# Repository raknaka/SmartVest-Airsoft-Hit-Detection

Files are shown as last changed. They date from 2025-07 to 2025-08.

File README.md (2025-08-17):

# 🎯 SmartVest - Airsoft Hit Detection System  

**SmartVest** is a smart wearable system designed for airsoft games and tactical training scenarios.  
It provides **real-time hit detection** by sensing BB pellet or rubber projectile impacts through an array of pressure and vibration sensors.  
Inspired by video game mechanics, SmartVest delivers immersive and measurable training by mapping impact zones and giving instant feedback to the player or trainer.  

---

## 🧩 Project Mockup  

Here's a visual mockup of the SmartVest system design:  

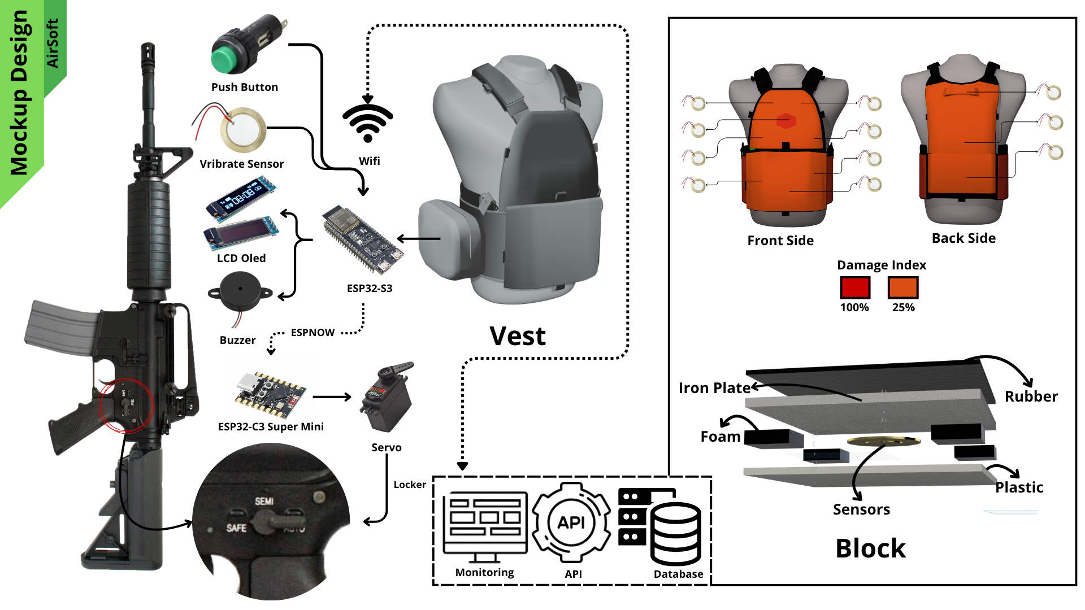
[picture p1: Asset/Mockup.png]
SmartVest Design Mockup
  

---

## 💡 What Does It Do?  

SmartVest detects and classifies hits from projectiles (BBs or rubber bullets) on a player’s body using multiple force and vibration sensors embedded within a vest. It is especially designed to:  

- **Track and identify projectile impacts**  
- **Map hit locations across multiple zones**  
- **Differentiate real hits from fake or foreign object contacts**  
- **Deliver immediate feedback (visual/audio)**  
- **Log and transmit hit data to a central server or controller**  

---

## 🚀 Features  

- 🔹 **Multi-zone sensor detection** across the vest  
- 🔹 **Impact classification** (projectile vs. non-projectile)  
- 🔹 **Wireless communication options**:  
  - **ESP-NOW** → ultra-fast (1–2 ms latency) between vest & gun  
  - **Wi-Fi** → real-time logging to server/dashboard  
  - **LoRa (optional)** → long-range outdoor operations  
- 🔹 **Customizable & modular system** → supports different body sizes, teams, and modes  
- 🔹 **Game-style feedback** → LEDs, buzzer, vibration  
- 🔹 **Weapon lock system** → disables gun when player is “eliminated”  

---

## ⚙️ System Architecture  

- **Vest Module (ESP32)**  
  Processes sensor data, tracks health, and gives feedback via buzzer, LEDs, or vibration.  

- **Weapon Module (ESP32-C3 Mini + Servo)**  
  Automatic lock/unlock mechanism to prevent eliminated players from shooting.  

- **Monitoring Dashboard (Server/Raspberry Pi)**  
  Displays real-time player health, team stats, and hit locations.  

---

## 🧪 Testing & Results  

### Projectile & Airsoft Testing  
- Works best at **5–10 m**.  
- Piezo sensors generate up to **14V**, while ESP32 ADC max is **3.3V** (4095).  
- Tested with **SIG Sauer P226 MK25 GBB handgun** (~100 m/s muzzle velocity).  
- Reliable detection at 5 m distance.  

### Heatmap Analysis  
- A **grid test** (60×60 mm and 100×200 mm) was used to simulate projectile impacts on the vest pad.  
- **Heatmaps** were generated using Python visualization to show impact distribution:  
  - **Center areas** (closest to the sensor) produce the highest ADC readings.  
  - **Edges of the pad** show weaker signals, sometimes too low to be detected.  
  - Vibrations propagate to neighboring pads, but the **highest ADC value always corresponds to the direct hit pad**.  
- This proves SmartVest can **localize hits accurately** by identifying the strongest signal zone.  

*(Add images of heatmap here, e.g. 60x60 grid & 100x200 pad results)*  

### ESP-NOW Communication  
- Average latency: **1–2 ms**, with occasional spikes up to 45 ms due to interference.  
- Still fast and stable enough for **real-time weapon lock & feedback**.  

---

## 📂 Repository Contents  

- `firmware/` → ESP32 & ESP32-C3 source code  
- `hardware/` → PCB design files  
- `docs/` → diagrams, mockups, and test results  

---

## 📸 Prototype & Dashboard  

(Add your prototype photos, PCB screenshots, heatmap images, and monitoring UI here)  

---

## ⚡ Conclusion  

SmartVest integrates **real-time hit detection**, **automatic weapon lock**, and **centralized monitoring** into one system.  
Through **heatmap testing**, the system shows reliable hit localization and clear differentiation of impact zones.  
It enhances **fairness, sportmanship, and immersion** in airsoft games by combining IoT technology with game-like mechanics.  

---

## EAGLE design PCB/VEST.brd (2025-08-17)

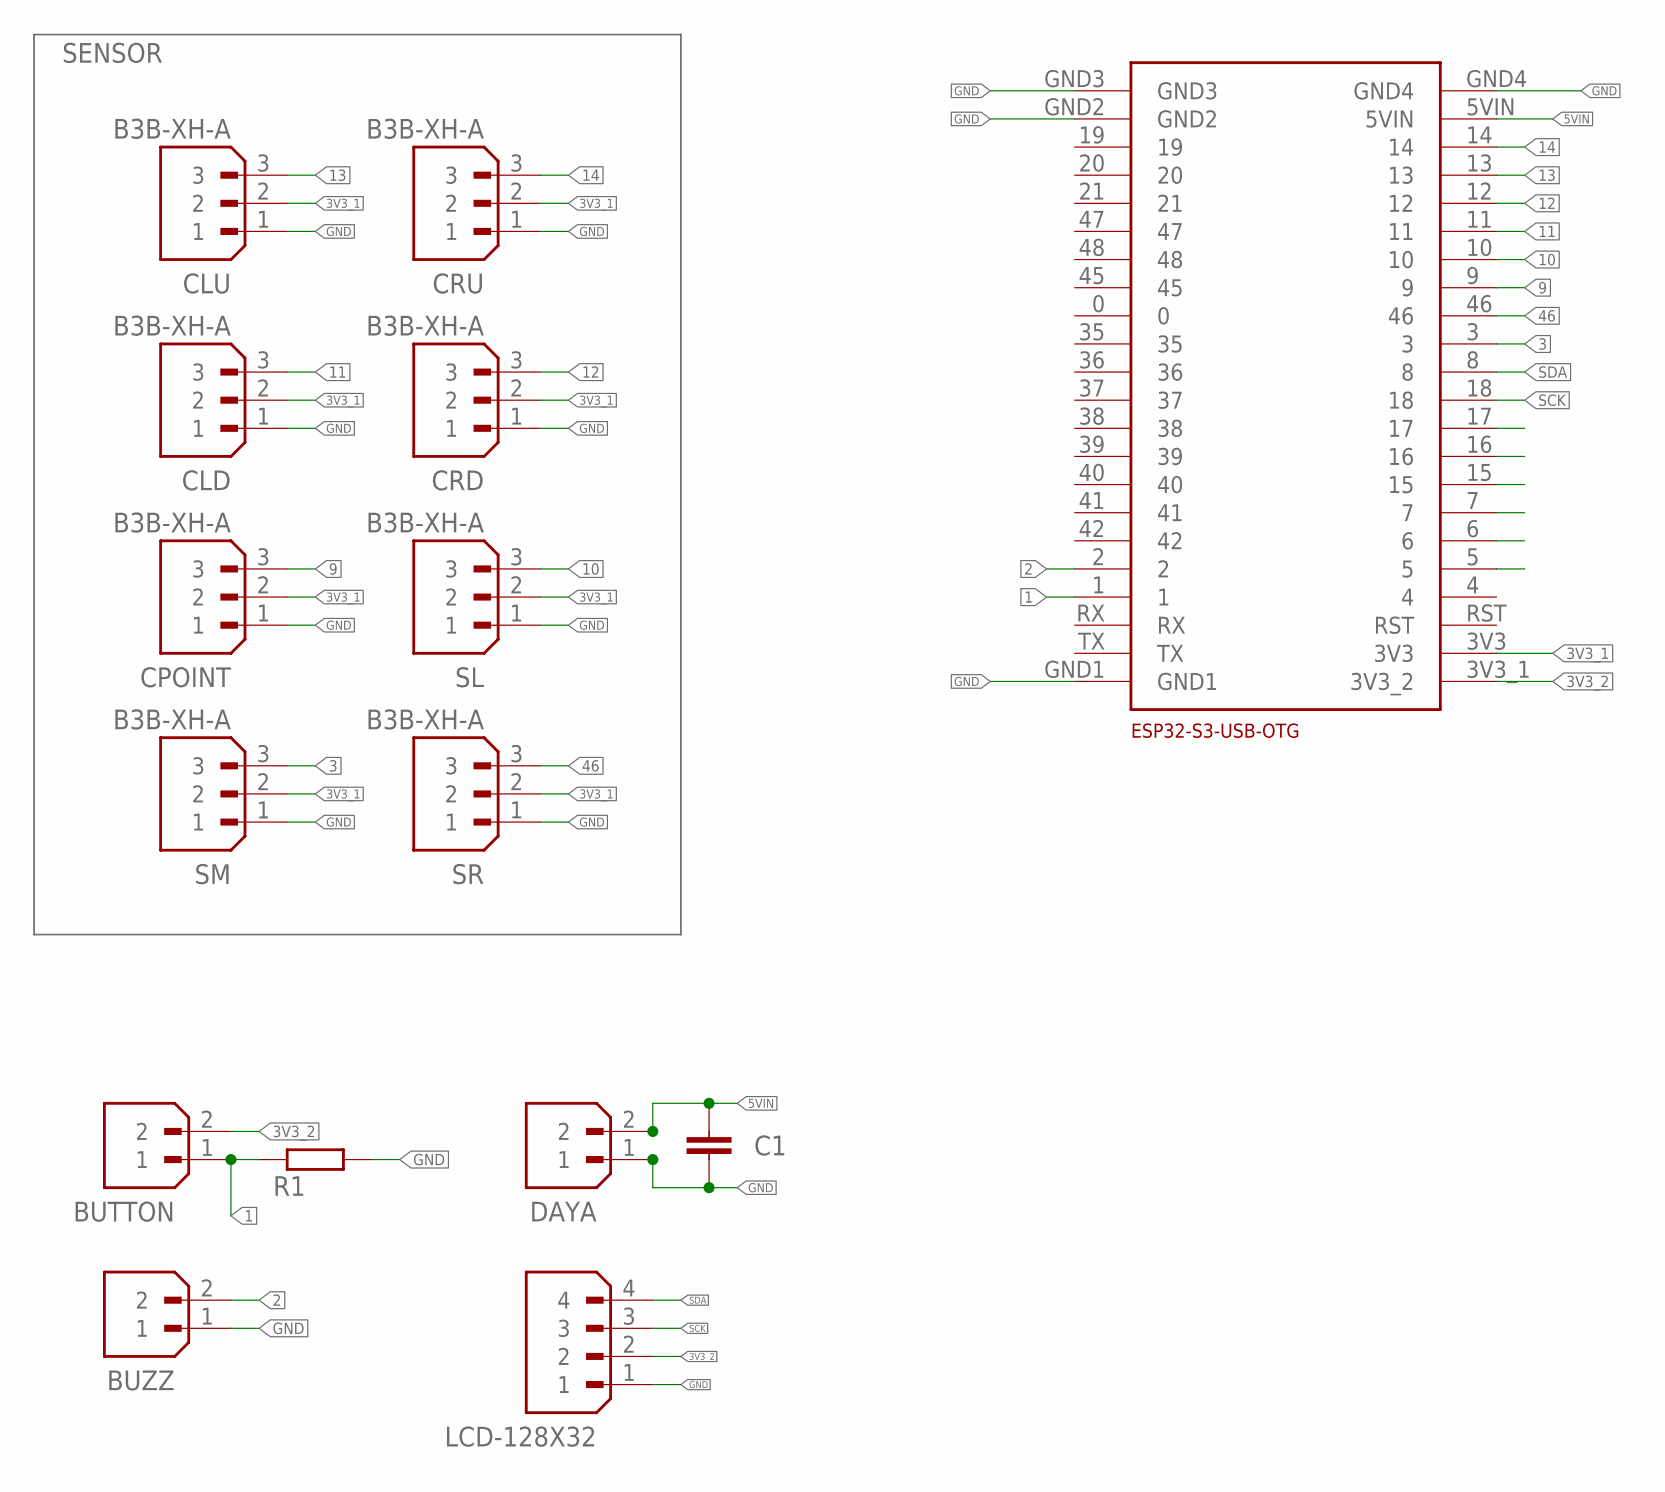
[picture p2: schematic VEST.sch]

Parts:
BUTTON: B2B-XH-A; JST_B2B-XH-A
BUZZ: B2B-XH-A; JST_B2B-XH-A
C1: C-EUC1206; C1206
CLD: B3B-XH-A; JST_B3B-XH-A
CLU: B3B-XH-A; JST_B3B-XH-A
CPOINT: B3B-XH-A; JST_B3B-XH-A
CRD: B3B-XH-A; JST_B3B-XH-A
CRU: B3B-XH-A; JST_B3B-XH-A
DAYA: B2B-XH-A; JST_B2B-XH-A
LCD-128X32: B4B-XH-A(LF)(SN); JST_B4B-XH-A(LF)(SN)
R1: R-EU_0207/10; 0207/10
SL: B3B-XH-A; JST_B3B-XH-A
SM: B3B-XH-A; JST_B3B-XH-A
SR: B3B-XH-A; JST_B3B-XH-A
U$1: ESP32-S3-DEVKIT; ESP32-S3-DEVKIT-USB-OTG

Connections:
1: BUTTON.1, R1.1, U$1.1
2: BUZZ.2, U$1.2
3: SM.3, U$1.3
3V3_1: CLD.2, CLU.2, CPOINT.2, CRD.2, CRU.2, SL.2, SM.2, SR.2, U$1.3V3
3V3_2: BUTTON.2, LCD-128X32.2, U$1.3V3_1 (3V3_2)
5VIN: C1.1, DAYA.2, U$1.5VIN
9: CPOINT.3, U$1.9
10: SL.3, U$1.10
11: CLD.3, U$1.11
12: CRD.3, U$1.12
13: CLU.3, U$1.13
14: CRU.3, U$1.14
46: SR.3, U$1.46
GND: BUZZ.1, C1.2, CLD.1, CLU.1, CPOINT.1, CRD.1, CRU.1, DAYA.1, LCD-128X32.1, R1.2, SL.1, SM.1, SR.1, U$1.GND1, U$1.GND2, U$1.GND3, U$1.GND4
SCK: LCD-128X32.3, U$1.18
SDA: LCD-128X32.4, U$1.8

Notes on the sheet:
SENSOR

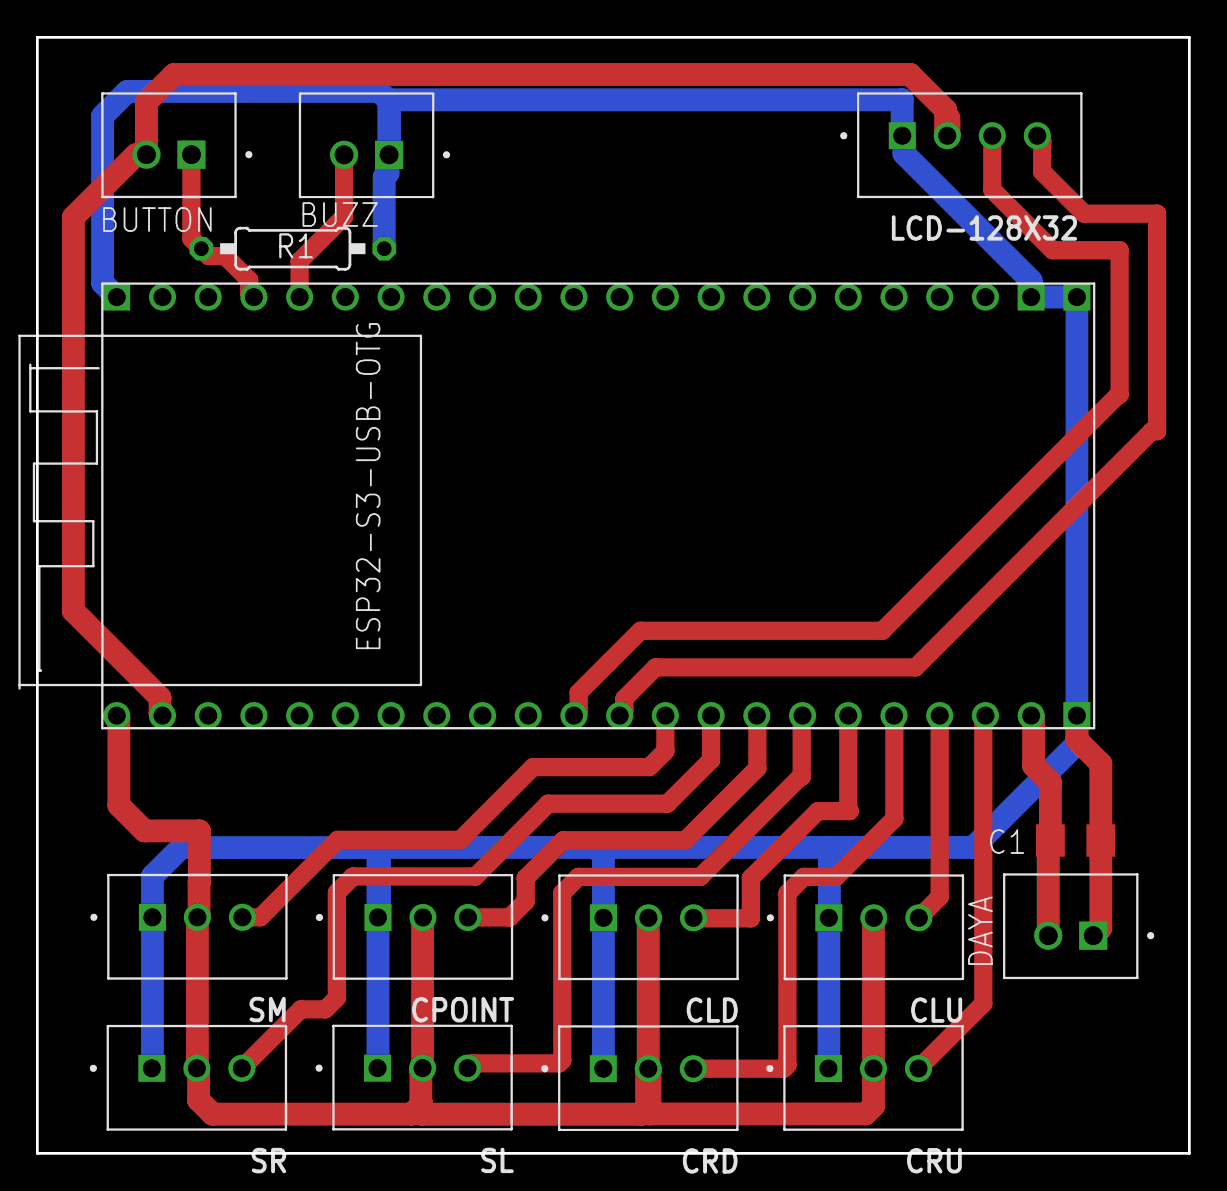
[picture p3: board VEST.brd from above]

Board: 2 copper layers, 64.0 x 62.0 mm, 15 parts (0 on the bottom side), 16 nets.

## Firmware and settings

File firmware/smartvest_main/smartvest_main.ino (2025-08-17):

#include <SPI.h>
#include <Wire.h>
#include <Adafruit_GFX.h>
#include <Adafruit_SSD1306.h>
#include <esp_now.h>
#include <WiFi.h>
#include <HTTPClient.h>

//Declar LCD
// Lebar dan tinggi OLED (sesuai spesifikasi modul Anda)
#define SCREEN_WIDTH 128
#define SCREEN_HEIGHT 32
// Inisialisasi OLED dengan alamat I2C (umumnya 0x3C atau 0x3D)
#define OLED_ADDRESS 0x3C
Adafruit_SSD1306 display(SCREEN_WIDTH, SCREEN_HEIGHT, &Wire);
//==============================================================================

// WiFi Configuration For SSID and Pass
const char *ssid = "mantab";
const char *password = "mantabjiwa123";

// Dev tunnel API list
String serverUrl1 = "https://l7xgct6c-3001.asse.devtunnels.ms/api/add/esp32";
String serverUrl2 = "https://l7xgct6c-3001.asse.devtunnels.ms/api/gameplay/status-by-mac";
String serverUrl3 = "https://l7xgct6c-3001.asse.devtunnels.ms/api/gameplay/status";
String serverUrl4 = "https://l7xgct6c-3001.asse.devtunnels.ms/api/hitpoint/healthUpdate";
// =====================================================

// //VPS Stas-RG API LIST
// String API = "https://api-vest.stas-rg.com";
// String serverUrl1 = API + "/api/add/esp32";
// String serverUrl2 = API + "/api/gameplay/status-by-mac";
// String serverUrl3 = API + "/api/gameplay/status";
// String serverUrl4 = API + "/api/hitpoint/healthUpdate";

// //Api LOCAL
// String ip = "localhost:3001";
// String serverUrl1 = "http://" + ip + "/VEST2/api/register_esp32.php";
// String serverUrl2 = "http://" + ip + "/api/update/update-status";
// String serverUrl3 = "http://" + ip + "/VEST2/api/status_esp.php";
// String serverUrl4 = "http://" + ip + "/api/update/update-health";

// Vibrate Sensor list pin
int vibratePins1 = 14;  // bahu kiri
int vibratePins2 = 13;  // bahu kanan
int vibratePins3 = 12;  // rusuk kiri
int vibratePins4 = 11;  // rusuk kanan
int vibratePins5 = 10;  // jantung
int vibratePins6 = 9;   // pinggang kiri
int vibratePins7 = 17;  // pinggang kanan
int vibratePins8 = 3;   // pusar



// Other Components
const int buttonPin = 2;
const int BUZZER_PIN = 1;

//System INIT
unsigned long previousMillis = 0;
const unsigned long interval = 10000;
int buttonPressed = 0;
int game_status = -1;
int weapon_update = 0;  // Ini gunannya buat biartau senjata udah dikunci apa belum,k
int health = 100;


//ESPNOW DECLARE
String macAddress;
uint8_t broadcastAddress[] = { 0xD8, 0x3B, 0xDA, 0x13, 0x68, 0x54 };  //esp32mini


// Struktur untuk komunikasi
typedef struct struct_message {
  int value;  // Nilai yang dikirimkan
} struct_message;

// Membuat struktur untuk mengirim dan menerima data
struct_message outgoingStruct;
struct_message incomingStruct;

//status status
int switchwifi = 0;
int switchespnow = 0;

//logo GAMBAR ++++++++++++++++++++++++++++++++++++++++++++++++++++++++++++++++++++++
// 'HEART2', 20x19px
const unsigned char epd_bitmap_HEART2[] PROGMEM = {
  0x1c, 0x38, 0x3e, 0x7c, 0x73, 0xfe, 0xe3, 0xff, 0xc7, 0xff, 0xc7, 0xff, 0xef, 0xff, 0x6f, 0xfe,
  0x7f, 0xfe, 0x3f, 0xfc, 0x1f, 0xf8, 0x0f, 0xf0, 0x07, 0xe0, 0x03, 0xc0, 0x01, 0x80
};

// 'Halfhearth', 16x15px
const unsigned char epd_bitmap_Halfhearth[] PROGMEM = {
  0x1c, 0x00, 0x3e, 0x00, 0x73, 0x00, 0xe3, 0x00, 0xc7, 0x00, 0xc7, 0x00, 0xef, 0x00, 0x6f, 0x00,
  0x7f, 0x00, 0x3f, 0x00, 0x1f, 0x00, 0x0f, 0x00, 0x07, 0x00, 0x03, 0x00, 0x01, 0x00
};

//gambar gembok
const unsigned char epd_bitmap_lock[] PROGMEM = {
  0x1f, 0x00, 0x31, 0x80, 0x20, 0x80, 0x20, 0x80, 0x20, 0x80, 0x7f, 0xc0, 0xf1, 0xe0, 0xe0, 0xe0,
  0xe0, 0xe0, 0xf1, 0xe0, 0xf1, 0xe0, 0xf1, 0xe0, 0x7f, 0xc0
};


// LOGO SMART VEST DI LCD DATA GAMBAR BITMAP
const unsigned char epd_bitmap_VEST[] PROGMEM = {
  0xff, 0xff, 0xff, 0xff, 0xff, 0xff, 0xff, 0xff, 0xff, 0xff, 0xff, 0xff, 0xff, 0xff, 0xff, 0xff,
  0x80, 0x00, 0x00, 0x00, 0x00, 0x00, 0x00, 0x00, 0x00, 0x00, 0x00, 0x00, 0x00, 0x00, 0x00, 0x01,
  0x80, 0x00, 0x00, 0x00, 0x00, 0x00, 0x00, 0x00, 0x00, 0x00, 0x00, 0x00, 0x00, 0x00, 0x00, 0x01,
  0x80, 0x00, 0x00, 0xf9, 0x8c, 0x03, 0xc7, 0xe0, 0x20, 0x00, 0x00, 0x40, 0x00, 0x00, 0x00, 0x01,
  0x80, 0x00, 0x00, 0x81, 0x9c, 0x62, 0x40, 0x80, 0x23, 0x20, 0x18, 0x40, 0x00, 0x00, 0x00, 0x01,
  0x80, 0x00, 0x00, 0xc1, 0xd6, 0x72, 0x40, 0x80, 0x22, 0x3f, 0xb1, 0xf8, 0x00, 0x00, 0x00, 0x01,
  0x80, 0x00, 0x00, 0x61, 0x52, 0x5b, 0xc0, 0x80, 0x26, 0x20, 0x20, 0x40, 0x00, 0x00, 0x00, 0x01,
  0x80, 0x00, 0x00, 0x19, 0x72, 0xf9, 0xfc, 0x80, 0x2c, 0x3c, 0x3c, 0x40, 0x00, 0x00, 0x00, 0x01,
  0x80, 0x00, 0x00, 0x09, 0x22, 0x89, 0x00, 0x80, 0x38, 0x20, 0x04, 0x60, 0x00, 0x00, 0x00, 0x01,
  0x80, 0x00, 0x00, 0x79, 0x02, 0x8d, 0x00, 0x00, 0x30, 0x3c, 0x7c, 0x3c, 0x00, 0x00, 0x00, 0x01,
  0x80, 0x00, 0x00, 0x00, 0x00, 0x00, 0x00, 0x00, 0x00, 0x00, 0x00, 0x00, 0x00, 0x00, 0x00, 0x01,
  0x80, 0x00, 0x00, 0x00, 0x00, 0x00, 0x00, 0x00, 0x00, 0x00, 0x00, 0x00, 0x00, 0x00, 0x00, 0x01,
  0x80, 0x00, 0x00, 0x00, 0x00, 0x00, 0x00, 0x00, 0x00, 0x00, 0x00, 0x00, 0x00, 0x00, 0x00, 0x01,
  0x80, 0x00, 0x00, 0x00, 0x00, 0x1f, 0xff, 0xff, 0xff, 0xff, 0xff, 0xff, 0xf0, 0x00, 0xe0, 0x01,
  0x80, 0x00, 0x00, 0x00, 0x00, 0xff, 0xff, 0xff, 0xff, 0xff, 0xff, 0xe0, 0x3e, 0x01, 0xe0, 0x01,
  0x80, 0x0f, 0xff, 0xff, 0xff, 0xff, 0xff, 0xff, 0xff, 0xff, 0xff, 0xc0, 0x39, 0xfe, 0xe0, 0x01,
  0x80, 0x1f, 0xff, 0xff, 0xfe, 0x3f, 0xa3, 0xff, 0x80, 0x00, 0x00, 0x00, 0x00, 0x00, 0x00, 0x01,
  0x80, 0x0f, 0xff, 0xff, 0x00, 0x3f, 0x82, 0x3f, 0xc0, 0x00, 0x00, 0x00, 0x00, 0x00, 0x00, 0x01,
  0x80, 0x0f, 0xfe, 0x00, 0x00, 0xfc, 0x00, 0x1f, 0xf0, 0x00, 0x00, 0x00, 0x00, 0x00, 0x00, 0x01,
  0x80, 0x07, 0x00, 0x00, 0x01, 0xf8, 0x00, 0x0f, 0xf8, 0x00, 0x00, 0x00, 0x00, 0x00, 0x00, 0x01,
  0x80, 0x00, 0x00, 0x00, 0x00, 0xf0, 0x00, 0x07, 0xff, 0x00, 0x00, 0x00, 0x00, 0x00, 0x00, 0x01,
  0x80, 0x00, 0x00, 0x00, 0x00, 0x00, 0x00, 0x00, 0xff, 0xe0, 0x00, 0x00, 0x00, 0x00, 0x00, 0x01,
  0x80, 0x00, 0x00, 0x00, 0x00, 0x00, 0x00, 0x00, 0x3f, 0xc0, 0x00, 0x00, 0x00, 0x00, 0x00, 0x01,
  0x80, 0x00, 0x00, 0x00, 0x00, 0x00, 0x00, 0x00, 0x07, 0x00, 0x00, 0x00, 0x00, 0x00, 0x00, 0x01,
  0x83, 0x90, 0xce, 0x03, 0x38, 0x00, 0x00, 0x00, 0x00, 0x00, 0x00, 0x00, 0x00, 0x00, 0x00, 0x01,
  0x82, 0x19, 0x28, 0x02, 0xa0, 0x00, 0x00, 0x00, 0x00, 0x00, 0x00, 0x00, 0x00, 0x00, 0x00, 0x01,
  0x83, 0x91, 0xee, 0x7b, 0x28, 0x00, 0x00, 0x00, 0x00, 0x00, 0x00, 0x00, 0x00, 0x00, 0x00, 0x01,
  0x80, 0x91, 0x22, 0x02, 0xa8, 0x00, 0x00, 0x00, 0x00, 0x00, 0x00, 0x00, 0x00, 0x00, 0x00, 0x01,
  0x83, 0x9d, 0x2e, 0x02, 0xb8, 0x00, 0x00, 0x00, 0x00, 0x00, 0x00, 0x00, 0x00, 0x00, 0x00, 0x01,
  0x80, 0x00, 0x00, 0x00, 0x00, 0x00, 0x00, 0x00, 0x00, 0x00, 0x00, 0x00, 0x00, 0x00, 0x00, 0x01,
  0x80, 0x00, 0x00, 0x00, 0x00, 0x00, 0x00, 0x00, 0x00, 0x00, 0x00, 0x00, 0x00, 0x00, 0x00, 0x01,
  0xff, 0xff, 0xff, 0xff, 0xff, 0xff, 0xff, 0xff, 0xff, 0xff, 0xff, 0xff, 0xff, 0xff, 0xff, 0xff
};

// Function Prototypes
void beepBuzzer(int duration);
void initLCD();
void drawHealthDisplay();
void drawfinish();
void OnDataRecv();
void switchToWiFi();
void switchToESPNow();
void sendMac();
void sendStatusPlayer(int statusReady);
void gameStatus();
void vibrateRead();
void sendHealth();
void handleGameStart();
void handleGameInProgress();
void handleGameFinished();

void setup() {
  pinMode(BUZZER_PIN, OUTPUT);
  digitalWrite(BUZZER_PIN, LOW);
  pinMode(buttonPin, INPUT_PULLUP);
  pinMode(vibratePins1, INPUT);
  pinMode(vibratePins2, INPUT);
  pinMode(vibratePins3, INPUT);
  pinMode(vibratePins4, INPUT);
  pinMode(vibratePins5, INPUT);
  pinMode(vibratePins6, INPUT);
  pinMode(vibratePins7, INPUT);
  pinMode(vibratePins8, INPUT);

  Serial.begin(115200);
  initLCD();
  WiFi.mode(WIFI_STA);
  switchToWiFi();
  macAddress = WiFi.macAddress();
  Serial.println("MAC Address: " + macAddress);
  sendMac();
}

void loop() {
  unsigned long currentMillis = millis();

  // Update game status tiap 10 detik sekali
  // if (currentMillis - previousMillis >= interval) {
  //   previousMillis = currentMillis;
  //   gameStatus();
  // }

  gameStatus();
  switch (game_status) {
    case 0:
      handleGameStart();
      break;
    case 1:
      handleGameInProgress();
      break;
    case 2:
      handleGameFinished();
      break;
    default:
      Serial.println("Unknown game status");
      break;
  }
  delay(100);
}

void switchToWiFi() {
  // Matikan ESP-NOW
  esp_now_deinit();
  Serial.println("ESP-NOW disabled");

  // Aktifkan WiFi
  WiFi.mode(WIFI_STA);
  WiFi.begin(ssid, password);

  // Animasi koneksi WiFi
  unsigned long startTime = millis();
  bool isConnected = false;

  while (!isConnected) {
    // Periksa status WiFi
    if (WiFi.status() == WL_CONNECTED) {
      isConnected = true;
      break;
    }
    // Tampilkan animasi "Connecting to WiFi..."
    // display.clearDisplay();
    // display.setTextSize(1);  // Normal 1:1 pixel scale
    // display.setTextColor(SSD1306_WHITE);
    // display.setCursor(0, 0);  // Start at top-left corner
    // display.print("Connecting to WiFi");

    // // Tambahkan titik-titik animasi
    // int elapsed = (millis() - startTime) / 500 % 4;  // Hitung indeks titik (0-3)
    // for (int i = 0; i < elapsed; i++) {
    //   display.print(".");
    // }

    // display.display();  // Update OLED
    // delay(100);         // Tunggu sebentar sebelum iterasi berikutnya
  }

  // // Tampilkan pesan berhasil
  // display.clearDisplay();

  // display.setTextSize(1);
  // display.setTextColor(SSD1306_WHITE);
  // display.setCursor(0, 0);
  // display.println(F("@Wifi Connect@"));
  // display.setCursor(0, 10);
  // display.print("IP: ");
  // display.println(WiFi.localIP());  // Tampilkan IP Address
  // display.display();

  // Log ke Serial Monitor
  Serial.println("WiFi connected. IP Address: " + WiFi.localIP().toString());
}

//LOGO DLL
void drawHealthDisplay() {
  display.clearDisplay();

  // Tampilkan teks Health
  display.setTextSize(1);
  display.setTextColor(SSD1306_WHITE);
  display.setCursor(0, 0);
  display.print("Health: ");
  display.print(health);

  int maxHearts = 5;      // Jumlah total hati
  int heartSpacing = 20;  // Jarak antar hati
  int heartX = 0;         // Posisi awal hati di sumbu X

  for (int i = 0; i < maxHearts; i++) {
    int hpPerHeart = 20;
    int heartThreshold = (i + 1) * hpPerHeart;

    if (health >= heartThreshold) {
      // Hati penuh
      display.drawBitmap(heartX, 12, epd_bitmap_HEART2, 16, 15, SSD1306_WHITE);
    } else if (health >= (heartThreshold - 10)) {
      // Hati setengah
      display.drawBitmap(heartX, 12, epd_bitmap_Halfhearth, 16, 15, SSD1306_WHITE);
    }

    heartX += heartSpacing;  // Pindah ke posisi hati berikutnya
  }

  switch (weapon_update) {
    case 0:
      display.drawBitmap(117, 0, epd_bitmap_lock, 11, 13, SSD1306_WHITE);
      break;
    case 3:
      display.drawBitmap(117, 0, epd_bitmap_lock, 11, 13, SSD1306_WHITE);
      beepBuzzer(100);
      break;
  }
  display.display();
}

void drawfinish() {
  display.clearDisplay();

  // Tampilkan teks Health
  display.setTextSize(2);
  display.setTextColor(SSD1306_WHITE);
  display.setCursor(3, 0);
  display.print("GAME OVER");
}

void switchToESPNow() {
  // Deklarasi broadcastAddress sebagai variabel lokal
  uint8_t receiverAddress[] = { 0xD8, 0x3B, 0xDA, 0x13, 0x68, 0x54 };

  // Matikan WiFi
  WiFi.disconnect();
  WiFi.mode(WIFI_STA);  // Set mode ke Station

  // Inisialisasi ESP-NOW
  if (esp_now_init() != ESP_OK) {
    Serial.println("Error initializing ESP-NOW");
    return;
  }
  // Set callback untuk pengiriman dan penerimaan data
  esp_now_register_send_cb(OnDataSent);
  esp_now_register_recv_cb(OnDataRecv);

  // Tambahkan peer (B) sebagai tujuan
  esp_now_peer_info_t peerInfo;
  memset(&peerInfo, 0, sizeof(peerInfo));
  memcpy(peerInfo.peer_addr, receiverAddress, 6);
  peerInfo.channel = 0;
  peerInfo.encrypt = false;

  if (esp_now_add_peer(&peerInfo) != ESP_OK) {
    Serial.println("Failed to add peer");
    return;
  }
  Serial.println("Peer added successfully");

  // outgoingStruct.value = 1;
  // esp_now_send(receiverAddress, (uint8_t *)&outgoingStruct, sizeof(outgoingStruct));
}


// Callback saat data diterima
void OnDataRecv(const esp_now_recv_info_t *info, const uint8_t *incomingData, int len) {
  memcpy(&incomingStruct, incomingData, sizeof(incomingStruct));
  Serial.print("Data received from B: ");
  Serial.println(incomingStruct.value);
  weapon_update = incomingStruct.value;
}

void SendDataESPNow(const uint8_t *receiverAddress, int weapon) {
  outgoingStruct.value = weapon;
  esp_now_send(receiverAddress, (uint8_t *)&outgoingStruct, sizeof(outgoingStruct));
}

// Callback saat data dikirim
void OnDataSent(const uint8_t *mac_addr, esp_now_send_status_t status) {
  Serial.print("Last Packet Send Status: ");
  Serial.println(status == ESP_NOW_SEND_SUCCESS ? "Success" : "Fail");
}

void beepBuzzer(int duration) {
  digitalWrite(BUZZER_PIN, HIGH);
  delay(duration);
  digitalWrite(BUZZER_PIN, LOW);
  delay(duration);
}

//Void inisialisasi LCD
void initLCD() {
  // Inisialisasi I2C dengan pin custom
  Wire.begin(8, 18);  // SDA = 8, SCL = 9

  // Inisialisasi layar OLED
  if (!display.begin(SSD1306_BLACK, OLED_ADDRESS)) {
    Serial.println(F("OLED tidak ditemukan! Pastikan koneksi benar."));
    while (true)
      ;  // Berhenti jika OLED tidak ditemukan
  }
}


void sendMac() {
  if (WiFi.status() == WL_CONNECTED) {
    HTTPClient http;
    http.begin(serverUrl1);
    http.addHeader("Content-Type", "application/x-www-form-urlencoded");
    String postData = "mac_address=" + macAddress;
    int httpResponseCode = http.POST(postData);
    if (httpResponseCode > 0) {
      String response = http.getString();
      Serial.println("Response: " + response);
    } else {
      Serial.println("Error Code: " + String(httpResponseCode));
    }
    http.end();
  } else {
    Serial.println("WiFi not connected, cannot send MAC address.");
  }
}

void sendStatusPlayer(int statusReady) {
  if (WiFi.status() == WL_CONNECTED) {
    HTTPClient http;
    http.begin(serverUrl2);
    http.addHeader("Content-Type", "application/json");
    String payload = "{\"mac_address\":\"" + macAddress + "\",\"status_ready\":" + String(statusReady) + "}";
    int httpResponseCode = http.POST(payload);
    if (httpResponseCode > 0) {
      Serial.println("POST request sent successfully");
      Serial.println("Response code: " + String(httpResponseCode));
    } else {
      Serial.println("Error in POST request");
    }
    http.end();
  } else {
    Serial.println("WiFi not connected!");
  }
}

void gameStatus() {
  if (WiFi.status() == WL_CONNECTED) {
    HTTPClient http;
    http.begin(serverUrl3);
    int httpResponseCode = http.GET();
    if (httpResponseCode > 0) {
      String payload = http.getString();
      int index = payload.indexOf("\"game_status\":");
      if (index != -1) {
        String value = payload.substring(index + 14);
        value = value.substring(0, value.indexOf('}'));
        game_status = value.toInt();
      }
    } else {
      Serial.println("Error in HTTP request: " + String(httpResponseCode));
    }
    http.end();
  } else {
    Serial.println("WiFi not connected!");
  }
}

void vibrateRead() {

  int bahukiri = analogRead(vibratePins1);       //14
  int bahukanan = analogRead(vibratePins2);      //13
  int rusukkiri = analogRead(vibratePins3);      //12
  int rusukkanan = analogRead(vibratePins4);     //11
  int jantung = analogRead(vibratePins5);        //10
  int pinggangkiri = analogRead(vibratePins6);   //9
  int pinggangkanan = analogRead(vibratePins7);  //17
  int pusar = analogRead(vibratePins8);          //3

  // Serial.print("Vibrate 100 point :");
  // Serial.println(vibrateValue1);
  // Serial.print("Vibrate 25 point :");
  // Serial.println(vibrateValue8);
  // Jika ada getaran kuat, kurangi health

  if (bahukiri >= 200 && health > 0) {
    health = max(0, health - 15);  // Bahu kiri, luka cukup serius (otot dan tulang)
    beepBuzzer(100);
    sendHealth(1);
  }
  if (bahukanan >= 300 && health > 0) {
    health = max(0, health - 15);  // Bahu kanan, luka cukup serius
    beepBuzzer(100);
    sendHealth(2);
  }
  if (rusukkiri >= 200 && health > 0) {
    health = max(0, health - 30);  // Rusuk kiri, bisa merusak paru-paru
    beepBuzzer(100);
    sendHealth(3);
  }
  if (rusukkanan >= 300 && health > 0) {
    health = max(0, health - 30);  // Rusuk kanan, dampak berat ke paru-paru dan hati
    beepBuzzer(100);
    sendHealth(4);
  }
  if (jantung >= 200 && health > 0) {
    health = 0;  // Jantung = instan kill
    beepBuzzer(100);
    sendHealth(5);
  }
  if (pinggangkiri >= 300 && health > 0) {
    health = max(0, health - 40);  // Pinggang kiri, bisa mengenai ginjal
    beepBuzzer(100);
    sendHealth(6);
  }
  if (pinggangkanan >= 300 && health > 0) {
    health = max(0, health - 40);  // Pinggang kanan, bisa mengenai hati atau ginjal
    beepBuzzer(100);
    sendHealth(7);
  }
  if (pusar >= 200 && health > 0) {
    health = max(0, health - 50);  // Pusar, bisa menyebabkan pendarahan fatal
    beepBuzzer(100);
    sendHealth(8);
  }

  if (health == 0) {
    switchToESPNow();
    SendDataESPNow(broadcastAddress, 0);
  }
}



void sendHealth(int hitpoint) {
  if (WiFi.status() == WL_CONNECTED) {
    HTTPClient http;
    http.begin(serverUrl4);
    http.addHeader("Content-Type", "application/x-www-form-urlencoded");

    // Format POST data dengan benar
    String postData = "mac_address=" + macAddress + "&health=" + String(health) + "&hitpoint=" + String(hitpoint);

    Serial.println("Sending Data: " + postData);  // Debugging

    int httpResponseCode = http.POST(postData);

    if (httpResponseCode > 0) {
      String response = http.getString();
      Serial.println("Data sent successfully!");
      Serial.println("Server Response: " + response);
    } else {
      Serial.print("HTTP POST failed. Error Code: ");
      Serial.println(httpResponseCode);
    }

    http.end();  // Selalu tutup koneksi setelah request selesai
  } else {
    Serial.println("WiFi not connected. Unable to send health data.");
  }
}


void handleGameStart() {
  bool buttonState = digitalRead(buttonPin);

  if (buttonPressed == 0) {
    display.clearDisplay();
    display.setTextColor(SSD1306_WHITE);
    display.setTextSize(1);
    display.setCursor(20, 13);
    display.print("PRESS THE BUTTON");
    display.display();
    // Kondisi jika tombol ditekan
    if (buttonState == HIGH) {
      buttonPressed = 1;
      sendStatusPlayer(1);
      Serial.println("Wait Button To Press...");

      // Menampilkan teks "Press Button" di OLED
      display.clearDisplay();
      display.setCursor(45, 13);
      display.println("SUCCESS");
      display.display();

      delay(200);  // Debounce singkat
    }
  }

  // Kondisi jika tombol dilepaskan
  else if (buttonState == LOW && buttonPressed == 1) {
    display.clearDisplay();
    for (int i = 0; i < 3; i++) {  // Animasi sebanyak 3 siklus
      display.setTextSize(1);
      display.setTextColor(SSD1306_WHITE);
      display.drawBitmap(0, 0, epd_bitmap_VEST, 128, 32, SSD1306_WHITE);
      display.setCursor(90, 20);
      display.print("Wait");
      for (int j = 0; j <= 2; j++) {
        display.print(".");
        display.display();  // Update tampilan
        delay(300);         // Tunggu 300ms per titik
      }

      display.clearDisplay();  // Bersihkan layar sebelum siklus berikutnya
    }
  }
}


void handleGameInProgress() {

  drawHealthDisplay();

  switch (weapon_update) {
    case 0:
      switch (switchespnow) {
        case 0:
          switchToESPNow();
          switchespnow = 1;
          break;
        case 1:
          SendDataESPNow(broadcastAddress, 1);
          break;
      }
      break;
    case 1:
      switch (switchwifi) {
        case 0:
          switchToWiFi();
          switchwifi = 1;
          break;  // Tambahkan break di sini
        case 1:
          vibrateRead();
          break;
      }
      break;
  }
}




void handleGameFinished() {
  drawfinish();
  switchToESPNow();
  SendDataESPNow(broadcastAddress, 0);
}

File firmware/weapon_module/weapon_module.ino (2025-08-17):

#include <esp_now.h>
#include <WiFi.h>
#include <ESP32Servo.h>  // Gunakan pustaka ESP32Servo

// Struktur untuk komunikasi
typedef struct struct_message {
  int value;  // Nilai yang dikirimkan
} struct_message;

// Membuat struktur untuk mengirim dan menerima data
struct_message outgoingStruct;
struct_message incomingStruct;

// Alamat MAC dari ESP32 pengirim (A)
uint8_t senderAddress[] = { 0x30, 0x30, 0xF9, 0x77, 0x0E, 0x24 };  // Ganti dengan MAC Address perangkat A

// Deklarasi servo
Servo myServo;
const int servoPin = 2;

void OnDataRecv(const esp_now_recv_info_t *info, const uint8_t *incomingData, int len) {
  memcpy(&incomingStruct, incomingData, sizeof(incomingStruct));
  Serial.print("Data received from VEST: ");
  int recieveVest = incomingStruct.value;
  Serial.println(recieveVest);

  switch (recieveVest) {
    case 0:
      // Gerakkan servo ke sudut 0 derajat
      myServo.write(0);
      Serial.println("Servo moved to 0 degrees");
      // Kirim nilai 3 ke perangkat A
      outgoingStruct.value = 3;
      esp_now_send(senderAddress, (uint8_t *)&outgoingStruct, sizeof(outgoingStruct));
      Serial.println("Sent value: 3 to A");
      break;
    case 1:
      // Gerakkan servo ke sudut 180 derajat
      myServo.write(180);
      Serial.println("Servo moved to 180 degrees");
      // Kirim nilai 1 ke perangkat A
      outgoingStruct.value = 1;
      esp_now_send(senderAddress, (uint8_t *)&outgoingStruct, sizeof(outgoingStruct));
      Serial.println("Sent value: 1 to VEST");
      break;
  }
}

// Callback saat data dikirim
void OnDataSent(const uint8_t *mac_addr, esp_now_send_status_t status) {
  Serial.print("Last Packet Send Status: ");
  Serial.println(status == ESP_NOW_SEND_SUCCESS ? "Success" : "Fail");
}

void setup() {
  // Inisialisasi Serial Monitor
  Serial.begin(115200);

  // Inisialisasi WiFi di mode Station
  WiFi.mode(WIFI_STA);

  // Inisialisasi ESP-NOW
  if (esp_now_init() != ESP_OK) {
    Serial.println("Error initializing ESP-NOW");
    return;
  }

  // Set callback untuk pengiriman dan penerimaan data
  esp_now_register_send_cb(OnDataSent);
  esp_now_register_recv_cb(OnDataRecv);

  // Tambahkan peer (A) sebagai tujuan
  esp_now_peer_info_t peerInfo;
  memset(&peerInfo, 0, sizeof(peerInfo));
  memcpy(peerInfo.peer_addr, senderAddress, 6);
  peerInfo.channel = 0;
  peerInfo.encrypt = false;

  if (esp_now_add_peer(&peerInfo) != ESP_OK) {
    Serial.println("Failed to add peer");
    return;
  }
  Serial.println("Peer added successfully");

  // Inisialisasi servo
  myServo.attach(servoPin, 500, 2400);  // Sesuaikan pulsa minimum & maksimum jika perlu
  Serial.println("Servo initialized");
}

void loop() {
  // Loop kosong, logika dijalankan melalui callback
}

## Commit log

2025-08-17 Add files via upload
    This is was the firmware for smartvest due to esp32 board
2025-08-17 Add files via upload
    This is was the pcb from the smartvest system this is just an input output from esp32 to all the component
    [VEST.brd, VEST.sch]
